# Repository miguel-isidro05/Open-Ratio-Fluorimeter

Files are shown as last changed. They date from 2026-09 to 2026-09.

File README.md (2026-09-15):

# Open-Ratio Fluorimeter

Repositorio de trabajo para la adaptación del fluorímetro ratiométrico de IO Rodeo. Reúne el firmware, las interfaces gráficas, las PCB, la carcasa y las evidencias experimentales desarrolladas durante la pasantía en la UPCH.

## Estado actual

Hay dos montajes documentados:

1. El IO Rodeo con PyBadge, pantalla integrada y adaptación para el sensor AS7341.
2. La versión de demostración con Arduino Mega 2560, AS7341, pantalla Nokia 5110, GUI de escritorio y cuatro placas LED intercambiables.

La PCB Excite V5 es la iteración más reciente del módulo de excitación y está orientada al uso de LED seleccionados por banda. La PCB Energy entrega las líneas de alimentación usadas por el montaje, incluida la alimentación de 5 V para el Arduino Mega y la línea de 12 V para la iluminación. La PCB Detector se conserva como avance de diseño, pero no forma parte del montaje actual porque la detección se realizará con un módulo AST.

## Contenido

| Sección | Contenido |
| --- | --- |
| [`Firmware/`](Firmware/) | Firmware del Arduino Mega y snapshots del IO Rodeo con PyBadge |
| [`Software/`](Software/) | GUI del Mega y GUI anterior para el IO Rodeo |
| [`Hardware/Electronics/`](Hardware/Electronics/) | PCB Excite, Energy y Detector, con sus iteraciones de fabricación |
| [`Hardware/3D_Models/`](Hardware/3D_Models/) | Carcasa final en STL |
| [`Experiments/`](Experiments/) | Videos, clips por LED, pósteres y datos registrados |
| [`Papers/`](Papers/) | Artículos de referencia reunidos para el proyecto |
| [`PROGRESS.md`](PROGRESS.md) | Cronología y relación entre versiones |
| [`VERIFICATION.md`](VERIFICATION.md) | Pruebas ejecutadas sobre la copia organizada |
| [`UPLOAD_CHECKLIST.md`](UPLOAD_CHECKLIST.md) | Revisión previa al commit y al envío a GitHub |

## Por dónde empezar

- Para reproducir la versión con Arduino Mega, consulta [`Firmware/Arduino_Mega_AS7341/`](Firmware/Arduino_Mega_AS7341/) y [`Software/Arduino_Mega_AS7341_GUI/`](Software/Arduino_Mega_AS7341_GUI/).
- Para revisar la progresión de la PCB de excitación, abre [`Hardware/Electronics/Excitation/README.md`](Hardware/Electronics/Excitation/README.md).
- Para ver la demostración por cada LED, abre [`Experiments/Arduino_Mega_4_LED/README.md`](Experiments/Arduino_Mega_4_LED/README.md).
- Para revisar el funcionamiento del IO Rodeo, abre [`Experiments/IO_Rodeo_AS7341/README.md`](Experiments/IO_Rodeo_AS7341/README.md).

## Criterio de archivo

Los nombres originales de los proyectos KiCad y de sus archivos de fabricación se conservaron para no romper referencias ni ocultar el historial. Las etiquetas de versión añadidas en esta organización describen el orden de trabajo encontrado en las carpetas. No sustituyen un número de revisión grabado en la PCB.

Los videos originales de cámara no se incluyen porque `IMG_7704.MOV` supera el límite habitual de GitHub. El repositorio contiene versiones H.264 más pequeñas, sin metadatos de ubicación, y un manifiesto con los hashes de los originales.

## Antes de usar el equipo

Revisa tensiones, polaridad, masa común y compatibilidad de niveles lógicos antes de energizar el montaje. Los archivos y las pruebas de software no certifican seguridad eléctrica, calibración óptica ni precisión metrológica.

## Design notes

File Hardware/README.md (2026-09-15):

# Hardware

## Electrónica

[`Electronics/`](Electronics/) contiene los proyectos KiCad y archivos de fabricación de Excite, Energy y Detector.

## Mecánica

[`3D_Models/Carcasa_v1/`](3D_Models/Carcasa_v1/) contiene la carcasa final en formato STL.

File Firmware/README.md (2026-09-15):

# Firmware

## Arduino Mega 2560

[`Arduino_Mega_AS7341/v1.0/`](Arduino_Mega_AS7341/v1.0/) contiene el sketch `.ino`, la implementación C++ y la prueba host del firmware usado con la GUI multicanal.

## IO Rodeo con PyBadge

[`IO_Rodeo_PyBadge/`](IO_Rodeo_PyBadge/) conserva tres estados:

- `reference_upstream`: referencia original del firmware multicanal. No se presenta como trabajo propio.
- `v2.0_tsl2591_gui`: snapshot con telemetría USB para la primera GUI de escritorio.
- `v3.0_as7341`: adaptación posterior con AS7341 a 90 grados y TSL2591 a 180 grados.

Los nombres `v2.0` y `v3.0` indican la secuencia de archivo dentro de este repositorio. Consulta el README de cada snapshot para conocer su función real.

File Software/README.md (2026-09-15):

# Software

## GUI para Arduino Mega y AS7341

[`Arduino_Mega_AS7341_GUI/v1.0/`](Arduino_Mega_AS7341_GUI/v1.0/) es la aplicación actual para el montaje de demostración. Muestra la telemetría multicanal, controla la adquisición y el PWM, refleja la Nokia y registra experimentos.

## GUI anterior para IO Rodeo y TSL2591

[`IO_Rodeo_TSL2591_GUI/v1.0/`](IO_Rodeo_TSL2591_GUI/v1.0/) es la primera interfaz PyQt para observar y controlar la copia TSL del firmware del PyBadge mediante USB CDC.

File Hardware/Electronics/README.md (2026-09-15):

# Electrónica

| Módulo | Función | Estado |
| --- | --- | --- |
| [`Excitation/`](Excitation/) | Etapa de excitación y montaje de LED | V5 es la iteración más reciente |
| [`Power/Energy/`](Power/Energy/) | Conversión y distribución de alimentación | Ruta final de FlatCAM conservada |
| [`Detection/Detector/`](Detection/Detector/) | Diseño de una etapa detectora | Archivada, no usada con el detector AST actual |

Los archivos KiCad conservan nombres internos como `Untitled` y `Excite_V1`. No se renombraron porque el nombre del archivo no basta para reconstruir todas sus referencias internas.

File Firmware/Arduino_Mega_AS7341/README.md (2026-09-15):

# Firmware para Arduino Mega y AS7341

La versión actual está en [`v1.0/`](v1.0/). El sketch usa un Arduino Mega 2560, un AS7341 y una pantalla Nokia 5110. La salida D11 controla la iluminación externa mediante PWM.

## Archivos principales

- `v1.0/firmware/mega_as7341_multichannel/mega_as7341_multichannel.ino`: entrada del sketch para Arduino IDE.
- `v1.0/firmware/mega_as7341_multichannel/firmware.cpp`: implementación del firmware.
- `v1.0/tests/firmware_host/`: dobles de las bibliotecas Arduino y prueba host.

## Cableado conservado en el firmware

| Señal | Arduino Mega 2560 |
| --- | --- |
| AS7341 SDA | D20 / SDA |
| AS7341 SCL | D21 / SCL |
| Nokia SCLK | D52 |
| Nokia DIN / MOSI | D51 |
| Nokia DC | D5 |
| Nokia CE | D4 |
| Nokia RST | D3 |
| PWM LED | D11 |

Verifica el voltaje admitido por cada módulo antes de conectarlo. La asignación de pines no certifica compatibilidad con lógica de 5 V.

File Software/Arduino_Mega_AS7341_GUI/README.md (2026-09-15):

# GUI para Arduino Mega y AS7341

La versión actual está en [`v1.0/`](v1.0/). Usa PyQt y un protocolo serial JSON Lines para controlar el firmware del Mega sin sustituir las lecturas realizadas por el microcontrolador.

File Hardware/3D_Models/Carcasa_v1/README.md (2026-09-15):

# Carcasa final

Archivo: [`carcasa_final.stl`](carcasa_final.stl)

El STL es binario y contiene 13 430 triángulos. Su caja envolvente es 36.30 x 38.80 x 58.90 unidades. El formato STL no declara unidades; si el modelo fue exportado en milímetros, esas dimensiones corresponden a milímetros.

Hash SHA-256 del archivo original y de esta copia:

```text
de2bfdceeedc73f0b56ba4e6553f56c1a85680b48ca6d725923ace9b68575b5c
```

Antes de imprimir, confirma unidades, orientación, tolerancias, agujeros y espacio para conectores y cableado.

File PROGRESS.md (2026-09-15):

# Progresión del proyecto

Esta cronología reúne fechas visibles en los respaldos, documentos y archivos del proyecto. Cuando una carpeta no tiene un registro formal de cambios, se describe solo lo que puede verificarse en sus artefactos.

## Abril de 2026

- 14 de abril: primeros respaldos de Excite V1 y Detector V1.
- 15 de abril: primera preparación de archivos Gerber, perforado y mecanizado para Excite y Energy.
- 21 al 22 de abril: segundas iteraciones de FlatCAM para Excite y Energy.
- 25 de abril: archivos de fabricación de Excite V3 y modelo STEP asociado.
- 27 de abril: respaldo posterior del proyecto KiCad Excite V1.

## Mayo de 2026

- 5 y 6 de mayo: consolidación de la ruta de fabricación final de Energy. La carpeta `flatcam_vfinal` conserva proyectos FlatCAM, mapas, pista y taladro.

## Agosto de 2026

- 26 de agosto: diseño de la comunicación serial y de la GUI UPCH.
- 27 de agosto: diseño de la adaptación para Arduino Mega, adquisición multicanal y pantalla externa.

## Septiembre de 2026

- 8 de septiembre: registro visual del IO Rodeo funcionando con el AS7341. También aparecen respaldos recientes del proyecto Excite.
- 11 de septiembre: control PWM de la salida LED desde la GUI y firmware Mega 2.3.0. Se añadieron trazabilidad de PWM y validaciones de compatibilidad.
- 12 de septiembre: módulos de experimentos, blancos, cocientes, calibración, resultados y controles de calidad. Quedó pendiente la validación óptica con el montaje real.
- 14 de septiembre: escala Y automática opcional en la GUI y registro de la demostración con cuatro placas LED.

## Relación entre ramas

| Rama | Controlador | Sensor principal | Pantalla | Software de escritorio |
| --- | --- | --- | --- | --- |
| IO Rodeo adaptado | PyBadge | AS7341 a 90 grados y TSL2591 a 180 grados | Integrada en el equipo | GUI TSL anterior, cuando se usa el firmware con telemetría |
| Demostración Mega | Arduino Mega 2560 | AS7341 | Nokia 5110 | GUI multicanal en PyQt |

## Estado de las PCB

- Excite V5 es la iteración de fabricación más reciente y se conserva como la versión actual para LED específicos por banda.
- Energy conserva la fuente KiCad, dos rutas FlatCAM previas, una ruta final y archivos para corte láser.
- Detector V1 se archiva como diseño no utilizado en el montaje AST actual.

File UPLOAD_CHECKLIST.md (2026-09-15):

# Lista de revisión para GitHub

## Contenido

1. Abre `README.md` y comprueba que la descripción del estado actual coincide con el montaje físico.
2. Revisa `PROGRESS.md` y completa cualquier fecha o cambio eléctrico que no esté registrado en los nombres de archivo.
3. Confirma que los cuatro clips representan el LED correcto. Los LED 3 y 4 no tienen longitud de onda nominal asignada porque el video no identifica el componente.
4. Revisa los datos de `Experiments/Arduino_Mega_4_LED/data/` y retira cualquier sesión que no deba publicarse.
5. Confirma la licencia de `Firmware/IO_Rodeo_PyBadge/reference_upstream/`.

## Archivos de macOS

`.DS_Store` está ignorado para archivos nuevos. Si el repositorio ya tenía copias rastreadas, Git seguirá mostrándolas hasta retirarlas del índice o restaurarlas. Revísalas por separado antes de usar `git add .`.

## Comprobaciones locales

```bash
git status --short
git diff --check
find . -type f -size +95M -print
```

No debería aparecer ningún archivo nuevo por encima de 95 MB. Los videos derivados actuales están por debajo de 46 MB cada uno.

## Preparar el commit

```bash
git add .
git status --short
git commit -m "Organiza avances del fluorimetro y documenta versiones"
git push
```

Revisa la lista de `git status` antes de confirmar. Este documento describe los comandos, pero no sustituye la revisión del contenido que se hará público.

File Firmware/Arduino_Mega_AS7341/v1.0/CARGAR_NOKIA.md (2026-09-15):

# Firmware Mega + AS7341 + Nokia 5110 - 2.3.0

El programa se sube al **Arduino Mega 2560**, no directamente a la Nokia.

1. Cierra la conexión de la GUI y el monitor serie del IDE.
2. Abre `firmware/mega_as7341_multichannel/mega_as7341_multichannel.ino` en Arduino IDE. Mantén `firmware.cpp` en la misma carpeta: contiene la implementación y el IDE lo compila junto al sketch.
3. Selecciona Arduino Mega or Mega 2560, procesador ATmega2560 y el puerto USB del equipo.
4. Pulsa Subir. Espera «Done uploading».
5. Reinicia la GUI actualizada y conecta el mismo puerto a 115200 baudios.
6. En **Adquisición en vivo**, verifica Ganancia, Integración y **PWM LED D11**. El valor inicial debe indicar 25 %.

La versión 2.3.0 conserva sin cambios la adquisición validada con la API pública de Adafruit, el orden F1-F8/CLEAR/NIR, 128x/300ms al iniciar y el watchdog. El único cambio funcional del firmware es que el PWM de D11 ahora puede ajustarse desde la GUI entre 0 y 100 %.

Cableado actual: AS7341 SDA→20, SCL→21. Nokia CLK→52, DIN→51, DC→5, CE→4, RST→3. La salida PWM del LED externo es D11 y comienza en 25 % (`analogWrite(64)`). GND común. La alimentación y adaptación de niveles dependen del módulo: no conectes señales de 5 V directamente a una Nokia o sensor que no las tolere.

**Iniciar grabación** y **Detener y guardar CSV** controlan el registro. **Pausar gráfica** no detiene la recepción ni el CSV. Cada fila conserva las diez bandas, fecha UTC, secuencia, tiempo del Mega, ganancia, integración, porcentaje PWM y valor PWM raw.

La escala vertical es manual y fija. La gráfica no inventa muestras intermedias: la frecuencia real depende de la integración y lectura del sensor. La validación física de la Nokia y sus niveles eléctricos queda pendiente de la prueba en el equipo.

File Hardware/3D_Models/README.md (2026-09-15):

# Modelos 3D

[`Carcasa_v1/`](Carcasa_v1/) contiene la carcasa final recibida para este estado del proyecto.

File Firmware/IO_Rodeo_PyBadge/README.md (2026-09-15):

# Firmware del IO Rodeo con PyBadge

## `reference_upstream`

Código de referencia del proyecto multichannel colorimeter. Se conserva para comparar la base con las adaptaciones de la UPCH. Revisa su licencia y README originales antes de redistribuirlo.

Consulta [`reference_upstream/ARCHIVE_NOTES.md`](reference_upstream/ARCHIVE_NOTES.md) antes de usar sus ejemplos.

## `v2.0_tsl2591_gui`

Snapshot basado en el firmware `latest` que agrega un segundo puerto USB CDC. Ese puerto permite a la primera GUI recibir telemetría y enviar cambios de modo, ganancia, integración y normalización.

## `v3.0_as7341`

Snapshot que añade AS7341 a 90 grados en el canal 3 del PCA9546A y conserva un TSL2591 a 180 grados en el canal 0. Incluye la opción `Multichannel 90`, con dos páginas para los diez canales del AS7341.

Para instalar un snapshot, copia su contenido completo a la raíz de `CIRCUITPY`. No mezcles archivos entre snapshots.

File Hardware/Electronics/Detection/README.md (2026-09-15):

# Detección

[`Detector/`](Detector/) conserva el diseño de la etapa detectora desarrollada durante la adaptación.

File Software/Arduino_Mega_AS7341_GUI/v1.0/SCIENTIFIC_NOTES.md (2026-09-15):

# Base experimental y límites

Documentos locales examinados en `../Papers`, relativos a la carpeta FIRMWARE_IORODEO. La adaptación de software no reproduce ni valida las prestaciones de esos instrumentos.

| PDF | Evidencia consultada | Aplicación en la GUI |
| --- | --- | --- |
| Ratiometric design.pdf | Zhou et al., 2026, DOI 10.1016/j.microc.2026.118982, página PDF 2: cocientes entre emisiones seleccionadas y referencias internas | Selección explícita de canales y orientación A/B. No se asignan automáticamente bandas a un fluoróforo. |
| low_cost_1.pdf | Chen et al., Talanta 269, 125447, páginas PDF 4 y 5: estándares de concentración, promediado, ajuste lineal y mediciones replicadas | Promedio de N lecturas posteriores al clic; desviación estándar guardada; calibración con estándares, R² y RMSE. |
| low_cost_2.pdf | Power et al., DOI 10.1039/d3ay00991b, página PDF 1: fluorómetro con varias fuentes LED y detección multiespectral | Identificación manual de LED y conservación de todos los canales. El cociente de dos excitaciones es una adaptación experimental, no una equivalencia validada con ese artículo. |
| low_cost_3.pdf | Faghir Hagh et al., DOI 10.1109/JSEN.2024.3403416, página PDF 1: distintas excitaciones, calibración con patrones y almacenamiento local | Separación de condiciones de iluminación, puntos trazables y exportación. No se reproducen LoRa, turbidez ni conversiones de pigmentos. |
| Open-JIP.pdf | Bates et al., DOI 10.1007/s11120-019-00673-2, página PDF 1: protocolo OJIP y rendimiento fotoquímico | Define una limitación: no calcular Fv/Fm ni OJIP desde capturas manuales lentas del AS7341. |

## Métodos implementados

- LED sucesivos: colocar LED A, esperar estabilidad, capturar; cambiar manualmente a LED B, esperar y capturar. R = media del canal A bajo LED A / media del canal B bajo LED B. Se pueden elegir el mismo canal o canales diferentes. La deriva entre exposiciones no se cancela automáticamente.
- Referencia óptica: Q = emisión medida / excitación de referencia medida. Ambas son capturas sucesivas del AS7341, conservadas con su configuración. Es un cociente instrumental, no eficiencia cuántica ni irradiancia calibrada. La geometría y la respuesta espectral deben caracterizarse experimentalmente.
- Blanco: no se permite usarlo como denominador. En Blanco y fondo se captura por separado, identificado por exposición. La corrección explícita conserva S = media(señal) - media(blanco), incluso si es negativa. Se exige igualdad de exposición, protocolo, ganancia, integración y PWM. Para corregir un cociente se seleccionan los blancos de A y B: R = (A - blanco A) / (B - blanco B). Señal y referencia corregidas deben ser positivas para informar ese cociente.
- Calibración: y = m c + b por mínimos cuadrados ordinarios, intercepto libre. Se requieren tres concentraciones distintas; cada clic de intensidad recoge una nueva captura. Los cocientes guardados solo pueden añadirse una vez por par de capturas. No se mezclan canales, métodos, unidades ni ajustes del sensor. Los estándares replicados se conservan como puntos separados.
- El R² y el RMSE describen el ajuste a esos puntos. No constituyen validación externa ni estimación de LOD/LOQ. Las N lecturas consecutivas de una captura no son N réplicas independientes del ensayo.

Cada captura conserva cuentas crudas, media, desviación estándar, secuencias, tiempo del dispositivo, hora de finalización de captura, etiqueta, ganancia, integración y protocolo óptico declarado. El CSV guarda la hora de recepción de cada lectura. Se rechazan cuentas de 65535, denominador cero y cambios de configuración. Esto no certifica ausencia de saturación analógica ni linealidad. Se usa la integración nominal reportada por el firmware; no se aplica una conversión radiométrica entre bandas.

## Resultados y calidad (2026-09-12)

Esta sección interpreta el experimento actual o un JSON recuperado. No modifica el firmware, las cuentas, la gráfica en vivo ni los controles validados.

- Señales y réplicas muestra componentes raw, blancos y restas; media, SD y número de lecturas; ganancia, integración, PWM, exposición e IDs. Con una sola lectura la SD se muestra como no disponible. La SD de una resta o cociente no se obtiene por propagación automática: no se ha caracterizado la dependencia entre las lecturas y exposiciones.
- Los resultados con el mismo ID de muestra y firma experimental se agrupan como repeticiones del ensayo completo. Se informa media, SD muestral y RSD = 100 SD / |media| con al menos dos ensayos. Un resultado A/B requiere capturas nuevas de ambos componentes. Si comparten señal o referencia, la estadística de réplicas se bloquea; si comparten blancos se advierte de posible correlación y deriva. La SD es descriptiva, no incertidumbre total ni precisión certificada.
- Calibración e interpretación muestra puntos, valores ajustados y residuos (medido menos ajustado), R² y RMSE = raíz de la media de residuos al cuadrado. Estima c = (y - b) / m solo con método y unidad compatibles y una captura que no pertenezca a los estándares. Se bloquea extrapolar y se retienen los límites de concentración calibrados. El ajuste es ordinario, no ponderado, y no certifica linealidad: deben revisarse residuos y controles independientes.
- El aviso de referencia baja compara el denominador con un umbral editable en cuentas (inicialmente 1). Es un criterio operativo que impide informar concentración desde un cociente de referencia baja; no constituye un límite validado de señal/ruido, detección o cuantificación. Se conservan el cociente y su evidencia.
- Un blanco o una señal corregida no positiva no recibe concentración. Tampoco se atribuye una firma completa de calibración a resultados históricos versión 2. Se recupera su evidencia y se recalcula lo verificable; para continuar un ensayo se necesitan capturas nuevas.
- Exportar resultados CSV conserva IDs, configuraciones, método, valor raw y derivado, blancos, estadísticas, advertencias y concentración cuando procede. Incluye capturas y resultados guardados, diferenciados por evidence_type; la fila de una captura que aparece también como componente de un resultado no es una réplica adicional. El destino inicial es records/. El JSON versión 3 contiene las lecturas completas y se valida contra ellas al recuperarlo. Un CSV de adquisición raw no contiene por sí solo la asignación de blancos, muestras y estándares necesaria para reconstruir el ensayo.

## Bibliografía de los cálculos nuevos

1. Chen, X., et al. (2024). *A low-cost and portable fluorometer based on an optical pick-up unit for chlorophyll-a detection*. Talanta, 269, 125447. [DOI](https://doi.org/10.1016/j.talanta.2023.125447). Archivo local low_cost_1.pdf, página PDF 5, secciones 2.5 y 3.1: diferencia entre promediado de lecturas y tres pruebas separadas por concentración. Se adapta esa distinción; no se transfieren sensibilidad, LOD ni prestaciones del instrumento publicado.
2. Cantwell, H. (ed.) (2025). *Blanks in Method Validation*, 2.ª ed. Eurachem. [Guía](https://www.eurachem.org/images/stories/Guides/pdf/MV_Guide_Blanks_supplement_2nd_ed_EN.pdf). Página PDF 11 (página impresa 4), sección 3: tipos y usos del blanco. La guía orienta su elección; la corrección rutinaria de baseline queda fuera de su alcance explícito (página PDF 10). No se cita como prescripción de nuestra fórmula de resta.
3. Marston, D. J., Slattery, S. D., Hahn, K. M., y Tsygankov, D. (2021). *Correcting Artifacts in Ratiometric Biosensor Imaging; an Improved Approach for Dividing Noisy Signals*. Frontiers in Cell and Developmental Biology, 9, 685825. [DOI](https://doi.org/10.3389/fcell.2021.685825), [texto completo](https://pmc.ncbi.nlm.nih.gov/articles/PMC8418531/). Ecuación 2: cociente con resta de fondo en ambos componentes. Resultados, apartados sobre división por señales débiles: corregir el fondo no elimina los artefactos de denominadores ruidosos. Se adapta la operación a cuentas del AS7341, no la validación de imagen celular ni el método NCF propuesto por los autores.
4. NIST/SEMATECH. *e-Handbook of Statistical Methods*, sección 2.3.6.6, [Using the calibration curve](https://itl.nist.gov/div898/handbook/mpc/section3/mpc366.htm). Respalda la inversión de y = a + b x para recuperar x con el mismo instrumento y proceso controlado. La GUI no incorpora todavía el cálculo completo de incertidumbre de la concentración.
5. Zhou, M., et al. (2026). *Ratiometric fluorescence arrays: a review of design strategies, signal decoding, mechanisms, and applications*. Microchemical Journal, 228, 118982. [DOI](https://doi.org/10.1016/j.microc.2026.118982). Archivo local Ratiometric design.pdf, página PDF 2: cocientes de emisiones y referencias internas. Un LED externo o una referencia capturada sucesivamente no garantizan autocorrección de deriva, geometría o potencia de excitación.
6. DeRose, P. C. (2008). *Standard Guide to Fluorescence: Instrument Calibration and Validation*. NISTIR 7458. [DOI](https://doi.org/10.6028/NIST.IR.7458). Referencia de alcance metrológico: los derivados de cuentas no equivalen a irradiancia, concentración universal ni eficiencia cuántica sin calibración y validación del sistema óptico.

Las referencias están disponibles dentro de Resultados y calidad, en Métodos y bibliografía. Consulta de páginas y PDFs realizada el 2026-09-12. Se verificaron los PDFs locales directamente con pdftotext; no se utilizó PaperQA2 para estas comprobaciones.

## Uso

Ejecutar `desktop_gui/app.py` con las dependencias del proyecto. En Experimentos y calibración, introducir el ID de muestra, el protocolo óptico y N lecturas. Mantener el ID al repetir un ensayo de la misma muestra. Exposición identifica la condición actual (LED, filtro y posición); no debe cambiar entre blanco y señal de esa condición. El protocolo general describe ambas exposiciones A/B y debe mantenerse durante el ensayo y la curva.

En Blanco y fondo, seleccionar el canal y capturar blanco y señal por separado. Seleccionar ambos registros y guardar intensidad corregida. Para LED sucesivos o Baseline y referencia, capturar A y B; si se desea corrección, marcarla y seleccionar el blanco de cada exposición. No hay asignación automática de blancos. Cada resultado exige un ensayo A/B nuevo. El firmware descarta la integración anterior al comando, espera la estabilización y etiqueta las muestras nuevas.

En Curva de calibración, elegir intensidad raw, intensidad con blanco o último cociente guardado. Introducir concentración conocida y unidad; guardar cada estándar, con al menos tres niveles distintos, y ajustar. Para medir una muestra desconocida no se añade un punto de concentración supuesta: se captura señal o un ensayo A/B y se consulta Resultados y calidad. Abrir un JSON recupera evidencia sin convertirla en ensayo activo. Guardar experimento JSON conserva la evidencia completa; los CSV entregan tablas de adquisición, estándares o derivados según el botón utilizado.

## Revisión de interfaz

| Antes | Después | Motivo |
| --- | --- | --- |
| Adquisición, controles y actividad en una única vista | Pestañas de adquisición y experimentos; etapas de captura explícitas | Separar la lectura en vivo de las acciones experimentales. |
| Selectores enviaban índices; CSV fallaba con campo extra | Envío de texto del selector y filas CSV planas probadas | Evitar comandos rechazados y pérdida de exportación. |
| Eje espectral equidistante | Posiciones por longitud de onda y exclusión de saturados | No representar separaciones espectrales falsas ni saturación como señal cuantitativa. |

Apple HIG orientó jerarquía, controles legibles y estados explícitos; Emil orientó respuestas inmediatas sin animaciones decorativas durante adquisición.

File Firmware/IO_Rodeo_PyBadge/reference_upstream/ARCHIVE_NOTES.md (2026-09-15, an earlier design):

# Notas de la referencia upstream

Esta carpeta conserva el código de referencia para comparación y atribución. No se presenta como una versión lista para cargar en el montaje actual.

`examples/configuration.json` contiene una coma final en el objeto original y no es JSON estricto. Se conserva para no ocultar una diferencia del material de referencia. Para el montaje adaptado, usa el archivo `configuration.json` del snapshot `v2.0_tsl2591_gui` o `v3.0_as7341` correspondiente.

El enlace a la imagen del README se ajustó a una ruta relativa para que funcione dentro de este repositorio. El código y la licencia se conservan en la carpeta.

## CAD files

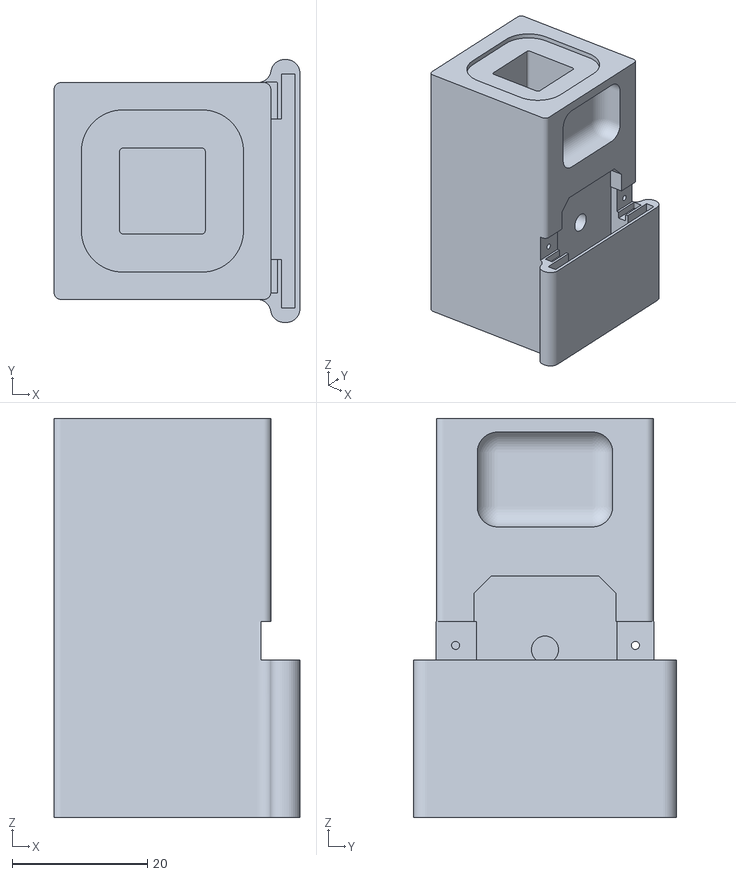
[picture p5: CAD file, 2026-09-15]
Hardware/3D_Models/Carcasa_v1/carcasa_final.stl
36.3 x 38.8 x 58.9

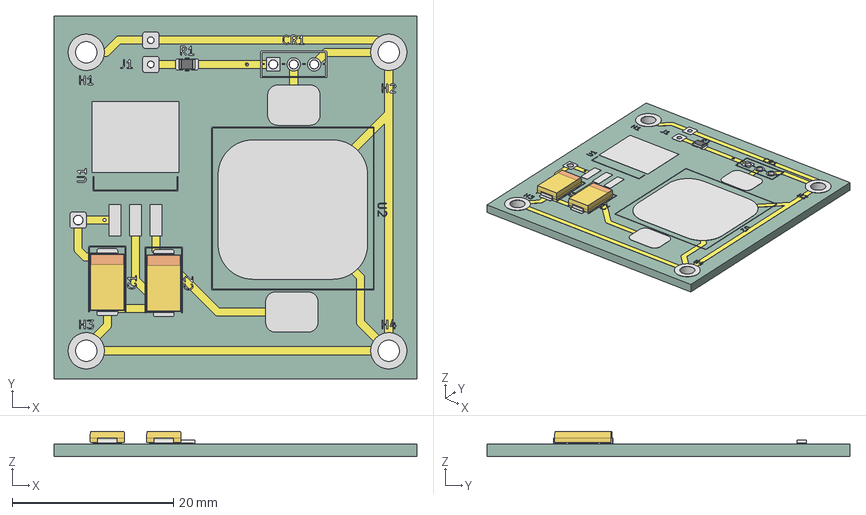
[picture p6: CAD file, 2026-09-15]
Hardware/Electronics/Excitation/Excite_V1/Excite_V1.step
45.0 x 45.0 x 3.13 mm
CP_EIA-7343-15_Kemet-W x 2
R_0805_2012Metric
Excite_V1_copper
Excite_V1_pad
Excite_V1_silkscreen
Excite_V1_PCB

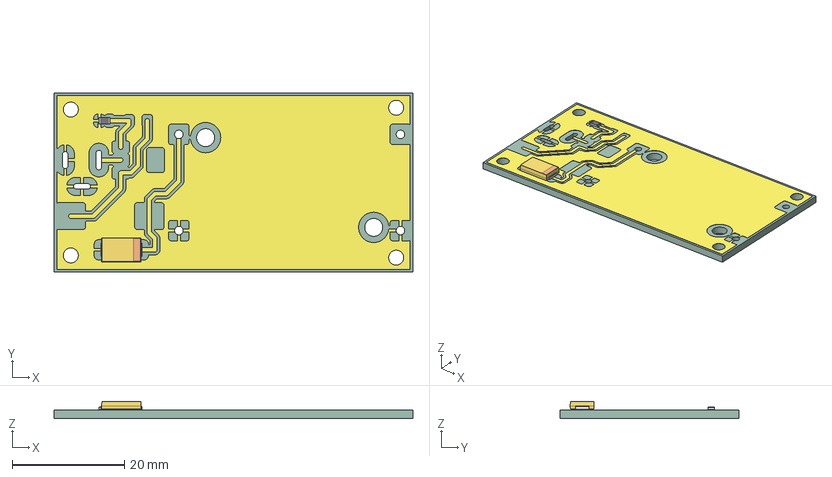
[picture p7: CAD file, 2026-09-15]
Hardware/Electronics/Power/Energy/Energia .step
64.0 x 32.0 x 3.09 mm
R_0805_2012Metric
CP_EIA-7343-15_Kemet-W
Untitled_copper
Untitled_PCB

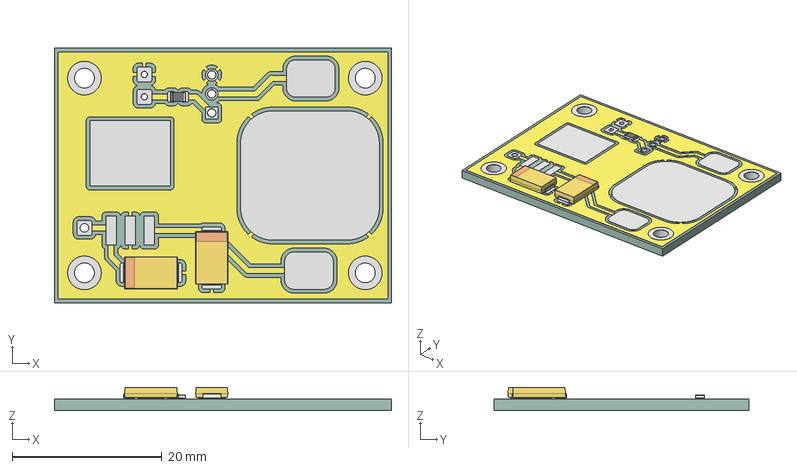
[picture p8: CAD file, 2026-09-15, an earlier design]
Hardware/Electronics/Excitation/flatcam_files_v3/Excite_V3.step
45.0 x 34.0 x 3.13 mm
CP_EIA-7343-15_Kemet-W x 2
R_0805_2012Metric
Excite_V1_copper
Excite_V1_pad
Excite_V1_PCB

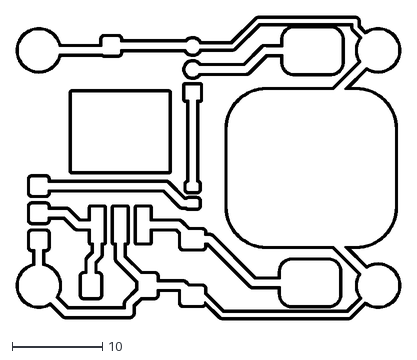
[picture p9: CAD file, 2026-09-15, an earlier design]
Hardware/Electronics/Excitation/flatcam_files_v4_laser/pista_1.DXF
42.5 x 33.5

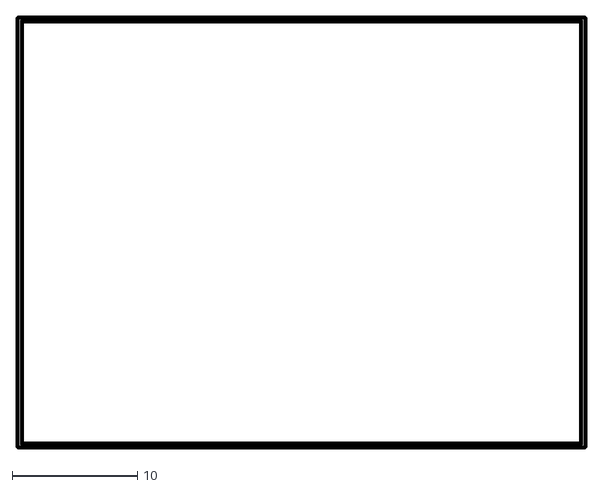
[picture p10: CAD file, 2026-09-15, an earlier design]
Hardware/Electronics/Excitation/flatcam_files_v4_laser/cut.DXF
45.6 x 34.6

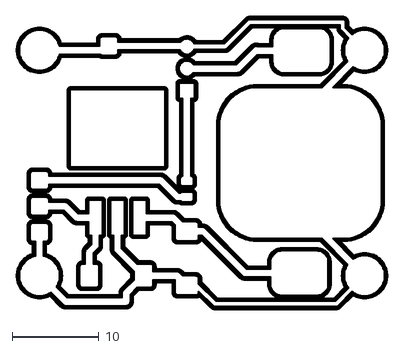
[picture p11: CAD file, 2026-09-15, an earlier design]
Hardware/Electronics/Excitation/flatcam_files_v4_laser/pista_2.DXF
42.8 x 33.8

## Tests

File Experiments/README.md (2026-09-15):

# Experimentos y demostraciones

## IO Rodeo con AS7341

[`IO_Rodeo_AS7341/`](IO_Rodeo_AS7341/) muestra el funcionamiento del equipo IO Rodeo con su pantalla integrada y el montaje óptico.

## Arduino Mega con cuatro LED

[`Arduino_Mega_4_LED/`](Arduino_Mega_4_LED/) contiene la demostración de la GUI, el Arduino Mega, el AS7341 y cuatro placas LED. El video original se dividió por etapa para que cada resultado pueda revisarse y enlazarse por separado.

Los videos son evidencia funcional, no una calibración de longitud de onda, potencia óptica ni linealidad.

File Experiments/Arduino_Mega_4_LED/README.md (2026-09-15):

# Demostración con Arduino Mega y cuatro LED

Esta demostración conecta el Arduino Mega 2560, el AS7341 y la GUI de escritorio. Cuatro placas LED se ensayan de forma sucesiva para observar el cambio de la respuesta multicanal.

## Montaje mostrado

- Arduino Mega 2560.
- Sensor AS7341.
- Pantalla Nokia 5110 conectada al firmware.
- GUI PyQt ejecutándose en la computadora.
- Cuatro placas LED intercambiables que no corresponden al LED de 12 V del módulo Excite final.

## Clips

| Etapa | Evidencia | Duración |
| --- | --- | ---: |
| LED 1, emisión azul visible | [`01_LED_AZUL.md`](01_LED_AZUL.md) | 39 s |
| LED 2, emisión ámbar visible | [`02_LED_AMBAR.md`](02_LED_AMBAR.md) | 64 s |
| LED 3 | [`03_LED_3.md`](03_LED_3.md) | 64 s |
| LED 4 | [`04_LED_4.md`](04_LED_4.md) | 34.17 s |

## Cómo reproducir la prueba

1. Carga el firmware de [`../../Firmware/Arduino_Mega_AS7341/v1.0/`](../../Firmware/Arduino_Mega_AS7341/v1.0/).
2. Instala e inicia la GUI de [`../../Software/Arduino_Mega_AS7341_GUI/v1.0/`](../../Software/Arduino_Mega_AS7341_GUI/v1.0/).
3. Conecta el puerto serial a 115200 baudios y espera la verificación del equipo.
4. Fija ganancia, integración y PWM. Anota cualquier cambio entre LED.
5. Con la alimentación desactivada, sustituye la placa LED.
6. Enciende la iluminación, espera estabilización y observa el espectro.
7. Inicia una grabación o captura experimental y guarda los datos.
8. Repite con el mismo montaje geométrico y condiciones comparables.

## Interpretación

Una variación en la curva demuestra que el sensor y la GUI responden al cambio de fuente. No permite asignar una longitud de onda nominal a cada LED ni comparar intensidades absolutas sin calibración, control de corriente, filtros y geometría constantes.

Los registros disponibles están en [`data/`](data/). Son datos de avance y deben revisarse antes de usarlos en un análisis científico.

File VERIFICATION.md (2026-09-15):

# Verificación de la copia organizada

Fecha de verificación: 14 de septiembre de 2026.

## Firmware del Arduino Mega

- Prueba C++ host aprobada: API pública del AS7341, canales raw, configuración, parser, display, barrera de captura y PWM.
- Compilación para `arduino:avr:mega` aprobada con Arduino AVR core 1.8.8.
- Uso informado por el compilador: 27 058 bytes de flash y 3 181 bytes de RAM estática.

## GUI

- GUI del Arduino Mega: 63 de 63 pruebas aprobadas en modo Qt offscreen.
- GUI histórica del IO Rodeo: 13 de 13 pruebas aprobadas.
- La prueba de integración de la GUI histórica se ajustó para localizar el firmware en `Firmware/IO_Rodeo_PyBadge/v2.0_tsl2591_gui/`. Una revisión independiente no encontró regresiones en ese cambio.

## Documentación y archivos

- 51 archivos Markdown revisados sin enlaces locales faltantes.
- Los archivos fuente copiados de Excite, Energy, Detector, firmware Mega y GUI Mega coinciden con sus originales, salvo exclusiones documentadas de cachés y archivos temporales.
- No hay archivos nuevos mayores de 95 MB.
- No se copiaron entornos virtuales, cachés Python, `fp-info-cache`, archivos `.kicad_prl` ni videos MOV originales.

## Medios

- Los cuatro clips del Mega y el video del IO Rodeo decodifican completos, con video y audio, sin errores de FFmpeg.
- Los derivados no contienen etiquetas de ubicación.
- Los intervalos y hashes de los originales están en `Experiments/MEDIA_MANIFEST.md`.

## Limitación conocida

`Firmware/IO_Rodeo_PyBadge/reference_upstream/examples/configuration.json` conserva una coma final del material de referencia y no es JSON estricto. No se usa como configuración de los snapshots adaptados.

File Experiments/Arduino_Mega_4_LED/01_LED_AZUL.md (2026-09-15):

# LED 1, emisión azul visible

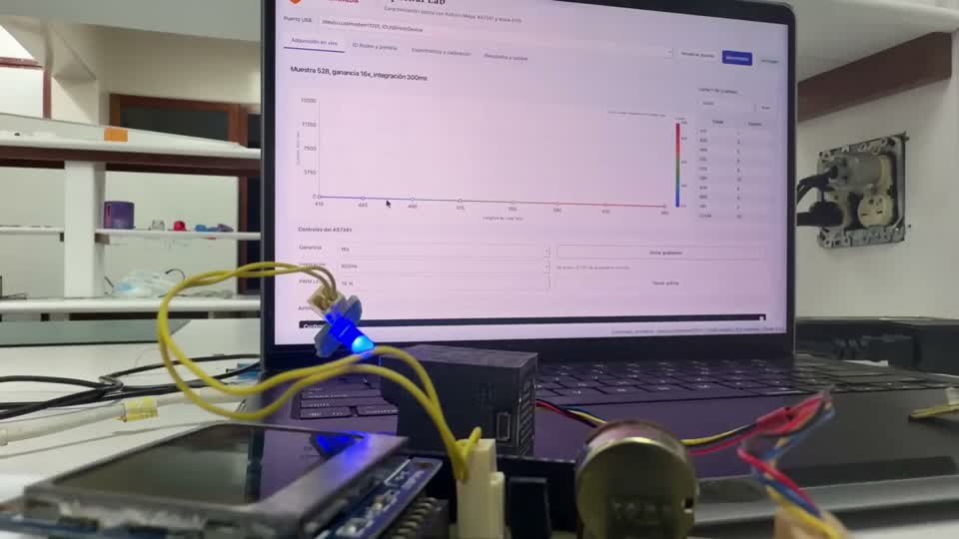
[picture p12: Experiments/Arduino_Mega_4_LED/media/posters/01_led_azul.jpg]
Demostración del LED azul


[Abrir el clip MP4](media/clips/01_led_azul.mp4)

Intervalo en el original: 00:00.000 a 00:39.000.

La placa emite luz azul visible frente al AS7341. La GUI recibe cuentas del firmware y representa la respuesta por bandas. El clip también muestra la manipulación previa al cambio de placa.

Para repetirlo, conserva la misma distancia y orientación entre LED y sensor. Registra ganancia, integración y PWM antes de guardar una captura.

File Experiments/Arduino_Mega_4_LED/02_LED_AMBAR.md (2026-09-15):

# LED 2, emisión ámbar visible

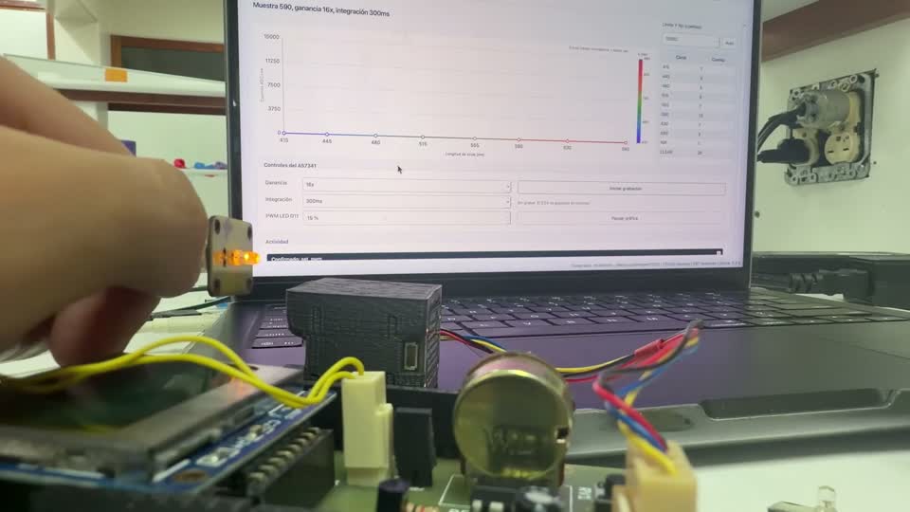
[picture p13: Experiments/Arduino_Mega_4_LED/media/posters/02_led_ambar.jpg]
Demostración del LED ámbar


[Abrir el clip MP4](media/clips/02_led_ambar.mp4)

Intervalo en el original: 00:39.000 a 01:43.000.

La segunda placa muestra una emisión ámbar visible. Durante esta etapa se observa la respuesta de la GUI y la interacción con sus controles.

El color observado por la cámara es una referencia visual. La banda central del LED debe confirmarse con su ficha técnica o una medición espectral calibrada.

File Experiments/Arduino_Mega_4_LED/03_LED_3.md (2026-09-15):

# LED 3

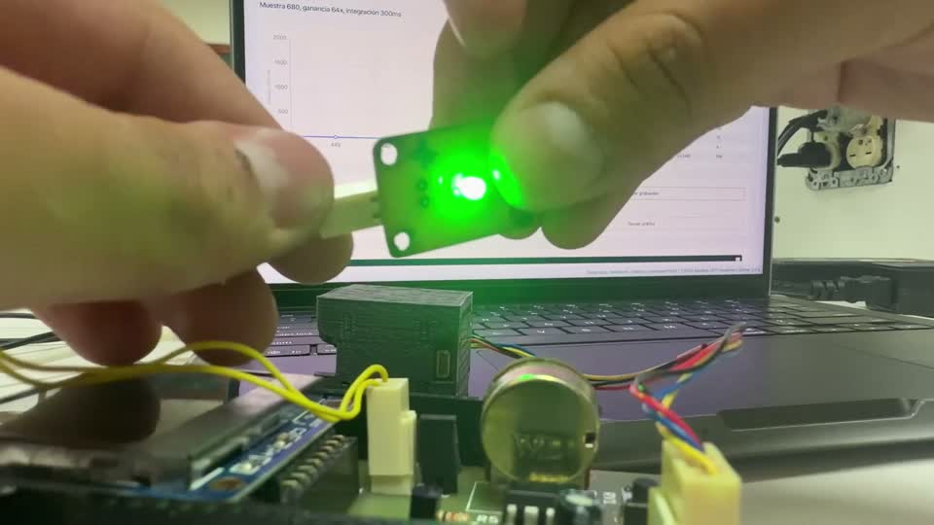
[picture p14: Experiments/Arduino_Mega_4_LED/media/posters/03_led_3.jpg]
Demostración del tercer LED


[Abrir el clip MP4](media/clips/03_led_3.mp4)

Intervalo en el original: 01:43.000 a 02:47.000.

La tercera placa se conecta y su emisión se observa como verde intensa en la cámara. La GUI muestra una distribución distinta de cuentas entre las bandas del AS7341.

No se asigna una longitud de onda nominal porque el video no aporta la identificación del componente. Documenta el código del LED y su corriente cuando se repita el ensayo.

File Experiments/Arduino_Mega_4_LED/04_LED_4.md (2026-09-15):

# LED 4

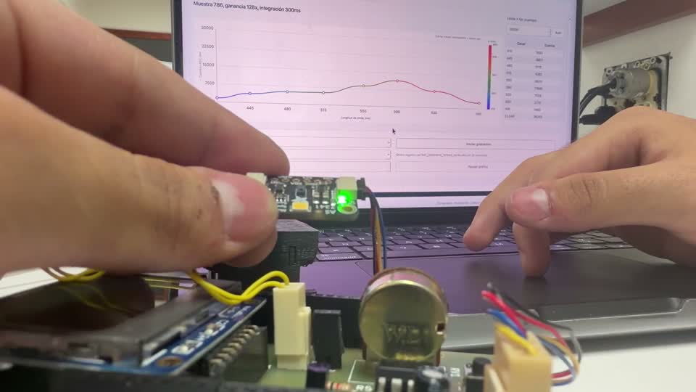
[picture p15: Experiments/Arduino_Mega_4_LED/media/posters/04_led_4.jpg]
Demostración del cuarto LED


[Abrir el clip MP4](media/clips/04_led_4.mp4)

Intervalo en el original: 02:47.000 a 03:21.165.

La cuarta placa tiene un diseño físico distinto. En el clip se observa una emisión verde y una curva amplia en la GUI. La etapa incluye la conexión, la presentación de la placa y la respuesta recibida.

La comparación con el LED 3 debe hacerse con los valores raw y la configuración guardada, no solo con la apariencia de la cámara.

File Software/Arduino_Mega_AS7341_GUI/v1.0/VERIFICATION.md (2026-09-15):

# Verificación de firmware y GUI

Fecha: 2026-09-14. Proyecto aislado; no se modificaron `upch_GUI` ni `upch_firmware`.

## Resultados

- 63 pruebas Python/Qt aprobadas en modo offscreen con el entorno `desktop_gui/.venv`.
- Seis pruebas de escala Auto: modo fijo inicial, ajuste y retorno manual, exclusión de NIR/Clear/OVFL, límites, pausa/reanudación, ausencia de comandos al firmware y transiciones animadas válidas o saturadas. Revisión visual del botón a 980 × 680 con datos simulados.
- Nuevas pruebas: resta con signo, blancos por exposición, cocientes corregidos, ensayos completos frente a lecturas seriales, no reutilización de señal como réplica, compatibilidad de calibración, inversión conocida y bloqueo de extrapolación/autopredicción del estándar.
- Recuperación v2→v3→recuperación verificada con cocientes y puntos. Un archivo con resultado/componentes alterados, firma incompatible o concentración excesiva se rechaza; la sesión actual se conserva.
- Exportación CSV verificada para resultados, captura raw de muestra desconocida y captura saturada (sin falsa concentración). El CSV diferencia filas de captura y resultado con `evidence_type`; ambas no deben contarse como réplicas adicionales.
- Revisión de código realizada; los hallazgos sobre blancos y números JSON excesivos se corrigieron y probaron.
- Prueba C++ con sensor, pantalla y UART simulados aprobada: API pública del AS7341, orden raw, ganancias, integraciones, parser, display, captura, negociación de capacidad y PWM D11 en 0 %, 25 %, 50 % y 100 %.
- Compilación real previa del 2026-09-11 para `arduino:avr:mega`, core AVR 1.8.8, con advertencias habilitadas: 27058 bytes de flash (10 %) y 3181 bytes de RAM estática (38 %). Esta ampliación no modifica el firmware ni requiere otra carga.
- Revisión visual offscreen de las secciones nuevas a 980 × 680 y 1100 × 900. Controles y tablas disponen de desplazamiento para conservar acceso a detalles e IDs. Las pruebas de adquisición, escala fija, pausa, grabación y espejo IO Rodeo siguen pasando.

## Repetir las pruebas

Desde la raíz de este proyecto, con PyQt6 y pyserial instalados:

```bash
QT_QPA_PLATFORM=offscreen PYTHONPATH=desktop_gui desktop_gui/.venv/bin/python -m unittest discover -s tests -v
clang++ -std=c++17 -Wall -Wextra -I tests/firmware_host -I .arduino/libraries/ArduinoJson/src tests/firmware_host/test_firmware.cpp -o /tmp/upch-as7341-firmware-test
/tmp/upch-as7341-firmware-test
ARDUINO_DIRECTORIES_USER="$PWD/.arduino" arduino-cli compile --fqbn arduino:avr:mega --warnings all firmware/mega_as7341_multichannel
```

Las versiones de bibliotecas están en README.md. En este Mac se usó el `arduino-cli` incluido en Arduino IDE, en `/Applications/Arduino IDE.app/Contents/Resources/app/lib/backend/resources/arduino-cli`.

## Estado de validación física

El usuario confirmó comunicación con el Mega, recepción multicanal, patrón azul, GUI y Nokia con la configuración anterior. El nuevo control PWM de la versión 2.3.0 está verificado por pruebas y compilación, pero falta cargarlo y comprobar físicamente D11 a 0 %, 25 %, 50 % y 100 %. El modo IO Rodeo reproduce el contenido multicanal disponible; no inventa batería, TSL a 180° ni Relative Units.

La corrección de fondo, las curvas y las estadísticas nuevas están verificadas con datos simulados y evidencia bibliográfica, no con estándares reales del montaje. Falta comprobar matriz del blanco, estabilidad, repetibilidad y controles independientes; no se informa LOD/LOQ, eficiencia cuántica ni incertidumbre certificada.

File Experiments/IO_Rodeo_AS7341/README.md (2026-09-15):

# Demostración del IO Rodeo

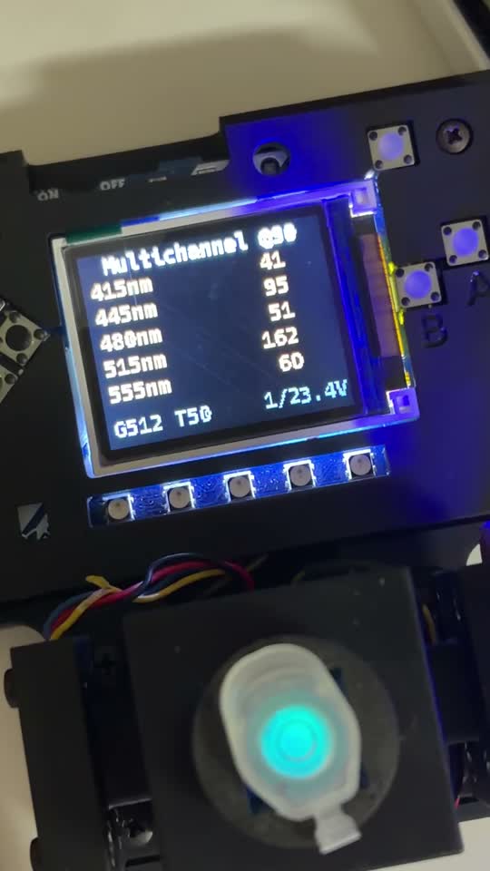
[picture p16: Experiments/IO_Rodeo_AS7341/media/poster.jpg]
IO Rodeo en funcionamiento


[Abrir el video MP4](media/demostracion_funcionamiento.mp4)

## Qué muestra

El video registra el equipo IO Rodeo encendido, la pantalla multicanal y el montaje óptico conectado. La pantalla presenta las bandas del AS7341 en páginas, mientras el conjunto mantiene el formato físico del fluorímetro.

## Firmware relacionado

Consulta [`../../Firmware/IO_Rodeo_PyBadge/v3.0_as7341/`](../../Firmware/IO_Rodeo_PyBadge/v3.0_as7341/) para el snapshot que añade `Multichannel 90` y el AS7341 a 90 grados.

## Comprobaciones de uso

1. Apaga el equipo antes de cambiar sensores o conexiones.
2. Confirma AS7341 en el canal 3 y TSL2591 en el canal 0 del PCA9546A.
3. Carga el snapshot completo en `CIRCUITPY`.
4. Inicia `Multichannel 90` y revisa ambas páginas.
5. Si aparece `OVFL`, reduce ganancia, tiempo de integración o intensidad óptica.

El video confirma operación visible del montaje. No demuestra calibración absoluta del AS7341 ni exactitud del cociente ratiométrico.

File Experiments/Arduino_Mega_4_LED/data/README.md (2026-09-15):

# Datos registrados

`records/` contiene CSV generados por la grabación de telemetría. `sessions/` conserva autoguardados de experimentos y, cuando existe, telemetría progresiva.

Antes de analizar estos archivos:

1. Comprueba que la sesión tenga identificador de muestra y configuración.
2. Separa lecturas sucesivas de réplicas experimentales completas.
3. Verifica ganancia, integración, PWM y canales.
4. Identifica blancos y exposiciones A/B cuando se use un cociente.
5. No interpoles lecturas `OVFL` ni extrapoles una curva de calibración.

Algunas sesiones son registros parciales de desarrollo. La presencia de un archivo no implica que el ensayo haya terminado o que cumpla un protocolo validado.

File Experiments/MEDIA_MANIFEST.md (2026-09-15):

# Manifiesto de medios originales

Los originales permanecen fuera del repositorio. Se registran sus hashes para comprobar que los clips proceden de los archivos correctos.

| Archivo original | Duración | Resolución y tasa | SHA-256 | Uso |
| --- | ---: | --- | --- | --- |
| `IMG_7660.MOV` | 7.518 s | 3840 x 2160, 60 fps | `97373979a640ff70cb354c0268efe7090922c1629f4382dc448e66fb32d91656` | Demostración corta del IO Rodeo |
| `IMG_7704.MOV` | 201.165 s | 3840 x 2160, 59.94 fps | `6ea71553eface19bb1c0285349036ac75526879f4405b5b395dfdda7497e571c` | Demostración del Mega y cuatro LED |

## Conversión

Los derivados se codificaron como H.264 con audio AAC, 30 fps y reproducción progresiva para facilitar su uso en GitHub. Los clips del Mega son 1920 x 1080. El video vertical del IO Rodeo es 1080 x 1920. Se retiraron los metadatos de ubicación de los derivados.

## Cortes de `IMG_7704.MOV`

| Clip | Intervalo del original |
| --- | --- |
| `01_led_azul.mp4` | 00:00.000 a 00:39.000 |
| `02_led_ambar.mp4` | 00:39.000 a 01:43.000 |
| `03_led_3.mp4` | 01:43.000 a 02:47.000 |
| `04_led_4.mp4` | 02:47.000 a 03:21.165 |

Los límites incluyen la sustitución física de cada placa LED para no perder la continuidad de la demostración.

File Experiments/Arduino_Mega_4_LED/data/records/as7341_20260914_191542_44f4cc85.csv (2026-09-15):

received_at | sequence | millis | gain | integration_time | pwm_percent | pwm_raw | page | 415 | 445 | 480 | 515 | 555 | 590 | 630 | 680 | nir | clear
2026-09-15T00:15:42.915046+00:00 | 741 | 535980 | 16x | 300ms | 15 | 38 | 0 | 399 | 185 | 2085 | 21882 | 6461 | 993 | 650 | 557 | 691 | 22030
2026-09-15T00:15:43.635001+00:00 | 742 | 536702 | 16x | 300ms | 15 | 38 | 0 | 399 | 185 | 2085 | 21882 | 6461 | 993 | 650 | 557 | 691 | 22030
2026-09-15T00:15:44.363257+00:00 | 743 | 537427 | 16x | 300ms | 15 | 38 | 0 | 399 | 185 | 2085 | 21883 | 6461 | 993 | 650 | 557 | 691 | 22031
2026-09-15T00:15:45.082473+00:00 | 744 | 538152 | 16x | 300ms | 15 | 38 | 1 | 399 | 185 | 2085 | 21882 | 6461 | 993 | 650 | 557 | 691 | 22030
2026-09-15T00:15:45.802971+00:00 | 745 | 538875 | 16x | 300ms | 15 | 38 | 1 | 399 | 185 | 2085 | 21881 | 6460 | 993 | 650 | 557 | 691 | 22030
2026-09-15T00:15:46.523459+00:00 | 746 | 539596 | 16x | 300ms | 15 | 38 | 1 | 399 | 185 | 2085 | 21880 | 6459 | 993 | 650 | 557 | 691 | 22025
2026-09-15T00:15:47.251730+00:00 | 747 | 540319 | 16x | 300ms | 15 | 38 | 1 | 399 | 185 | 2085 | 21878 | 6459 | 993 | 650 | 557 | 691 | 22026
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

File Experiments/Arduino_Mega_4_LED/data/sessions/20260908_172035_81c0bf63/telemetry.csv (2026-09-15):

received_at | sequence | millis | gain | integration_time | page | 415 | 445 | 480 | 515 | 555 | 590 | 630 | 680 | nir | clear
2026-09-08T22:26:50.319878+00:00 | 1 | 355 | 128x | 100ms | 0 | 6 | 14 | 18 | 24 | 6 | 14 | 18 | 24 | 23 | 117
2026-09-08T22:26:50.669815+00:00 | 2 | 709 | 128x | 100ms | 0 | 6 | 14 | 18 | 24 | 6 | 14 | 18 | 24 | 23 | 117
2026-09-08T22:26:51.045951+00:00 | 3 | 1063 | 128x | 100ms | 0 | 6 | 14 | 18 | 24 | 6 | 14 | 18 | 24 | 23 | 117
2026-09-08T22:26:51.396293+00:00 | 4 | 1419 | 128x | 100ms | 0 | 6 | 14 | 18 | 24 | 6 | 14 | 18 | 24 | 23 | 117
2026-09-08T22:26:51.745920+00:00 | 5 | 1773 | 128x | 100ms | 0 | 6 | 14 | 18 | 24 | 6 | 14 | 18 | 24 | 23 | 116
2026-09-08T22:26:52.094827+00:00 | 6 | 2127 | 128x | 100ms | 0 | 6 | 14 | 18 | 24 | 6 | 14 | 18 | 24 | 23 | 117
2026-09-08T22:26:52.445872+00:00 | 7 | 2482 | 128x | 100ms | 0 | 6 | 14 | 18 | 24 | 6 | 14 | 18 | 24 | 22 | 116
2026-09-08T22:26:52.820282+00:00 | 8 | 2836 | 128x | 100ms | 0 | 6 | 14 | 18 | 24 | 6 | 14 | 18 | 24 | 22 | 115
2026-09-08T22:26:53.171103+00:00 | 9 | 3190 | 128x | 100ms | 1 | 6 | 14 | 18 | 24 | 6 | 14 | 18 | 24 | 22 | 115
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

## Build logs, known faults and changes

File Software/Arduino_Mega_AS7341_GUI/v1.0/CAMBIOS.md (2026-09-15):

# Registro de cambios

## 2026-09-14 - Escala Y automática opcional

- Se añadió el botón Auto junto al límite Y. Está desactivado al abrir la GUI; se conserva el máximo fijo inicial de 2000 cuentas.
- Auto ajusta el máximo a F1-F8 con un margen del 10 % y redondeo hacia arriba. Excluye NIR, Clear y lecturas OVFL; el límite no supera 65535 cuentas.
- El estado activo se distingue por texto y color. Al desactivarlo, el último máximo queda disponible para ajuste manual. Pausar la gráfica también congela su escala automática.
- Se evita interpolar entradas y salidas de saturación para no generar valores visuales falsos. La animación entre lecturas válidas conserva su comportamiento.
- No se cambiaron ganancia, integración, PWM, datos raw, grabación ni firmware. No hace falta volver a cargar el Mega.

## 2026-09-12 - Experimentos, resultados y calidad

- Se ampliaron Experimentos y calibración con ID de muestra, exposición, capturas de blanco y señal, intensidad corregida y blancos A/B explícitos para ambos modos de cociente.
- La curva permite intensidad raw, intensidad con blanco o cociente. Cada punto conserva concentración, unidad, método y evidencia; la compatibilidad incluye ganancia, integración, PWM, canales y protocolo/exposiciones declarados.
- Se añadió Resultados y calidad: componentes raw y restas, estadísticas de ensayos completos, advertencias, inversión de curva compatible sin extrapolación, residuos y exportación de derivados a CSV.
- Se conservan las restas negativas y se distinguen lecturas de captura de réplicas completas. No se presentan LOD/LOQ, eficiencia cuántica ni incertidumbre certificada.
- Se documentaron las fórmulas, su adaptación al AS7341 y las referencias verificadas en SCIENTIFIC_NOTES.md y en la GUI.
- El JSON versión 3 conserva blancos e intensidades derivadas; los archivos versión 2 se recuperan sin inventar una firma de calibración ausente. La carga valida datos derivados contra las lecturas originales y conserva la sesión actual si el archivo es inválido.
- No se cambiaron firmware, Nokia, adquisición en vivo, curva espectral, escala, animación, ganancia, integración ni PWM.

Validación física pendiente: blancos, estándares y réplicas con el montaje real. Las pruebas de software no validan respuesta óptica, matriz ni precisión experimental.

## 2026-09-12 - Puntuación de la interfaz

- Se sustituyeron los puntos medios decorativos por comas, dos puntos o paréntesis.
- El subtítulo describe el equipo sin barras: Caracterización óptica con Arduino Mega, AS7341 y Nokia 5110.
- Se conservaron los cocientes, unidades, rutas y toda la configuración de adquisición y gráfica.

## 2026-09-11 - PWM regulable, firmware 2.3.0

Estado de partida confirmado:

- La lectura AS7341, las ganancias, los tiempos de integración, la gráfica espectral y su escala quedan congelados sin cambios.
- La salida efectiva del firmware actual es D11 con `analogWrite(64)`, equivalente a 25 %.

Cambios realizados:

- Se añadió el comando serial `set_pwm` con rango entero 0-100 %.
- La conversión usa todo el rango de Arduino: 0 % = 0, 25 % = 64 y 100 % = 255.
- La GUI incorpora **PWM LED D11** debajo de Integración y comienza en 25 %.
- `state`, telemetría y CSV incorporan `pwm_percent` y `pwm_raw` para mantener trazabilidad experimental.
- Un cambio PWM cancela una captura experimental pendiente, igual que cambiar ganancia o integración, para no mezclar condiciones ópticas.
- Cada captura registra el PWM y las curvas exigen mantener la misma configuración. En cocientes A/B se conserva por separado el PWM usado en A y en B.
- La GUI exige que el firmware anuncie la capacidad `pwm_control`; así no presenta como compatible una versión anterior que no entienda el comando.

Pendiente:

- Cargar firmware 2.3.0 en el Mega y confirmar físicamente D11 a 0 %, 25 %, 50 % y 100 %.

## 2026-09-11 - Identidad visual del encabezado

- Se reemplazó el texto `UPCH / Spectral Lab` por el logotipo institucional proporcionado y el nombre **Spectral Lab**.
- Se aplicó una tipografía serif académica, un separador discreto y márgenes compactos.
- No se modificaron la gráfica, la adquisición, el firmware ni los controles validados.

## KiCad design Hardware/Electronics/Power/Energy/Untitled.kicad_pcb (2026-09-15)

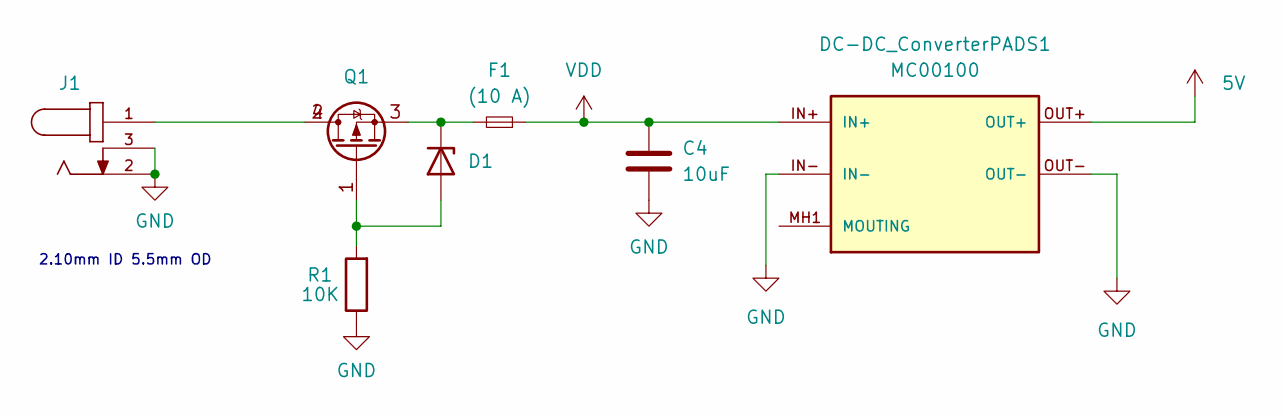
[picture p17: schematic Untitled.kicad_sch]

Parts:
C4: 10uF; C_0805_2012Metric
D1: D_Zener; MMSZ4700T1G
DC-DC_ConverterPADS1: MC00100; CONV_MC00100; PARTREV NA
F1: (10 A); 0154010.DRL; Part 0154010.DRL
J1: PJ-002A
Q1: DMP6023LE-13
R1: 10K; R_0805_2012Metric

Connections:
5V: DC-DC_ConverterPADS1.OUT+
GND: C4.2, DC-DC_ConverterPADS1.IN-, DC-DC_ConverterPADS1.OUT-, J1.2, J1.3, R1.1
unnamed: D1.2 (A), Q1.1, R1.2
unnamed: D1.1 (K), F1.2, Q1.3
unnamed: DC-DC_ConverterPADS1.MH1 (MOUTING), DC-DC_ConverterPADS1.MH2 (MOUTING)
unnamed: J1.1, Q1.2, Q1.4
VDD: C4.1, DC-DC_ConverterPADS1.IN+, F1.1

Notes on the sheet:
2.10mm ID 5.5mm OD

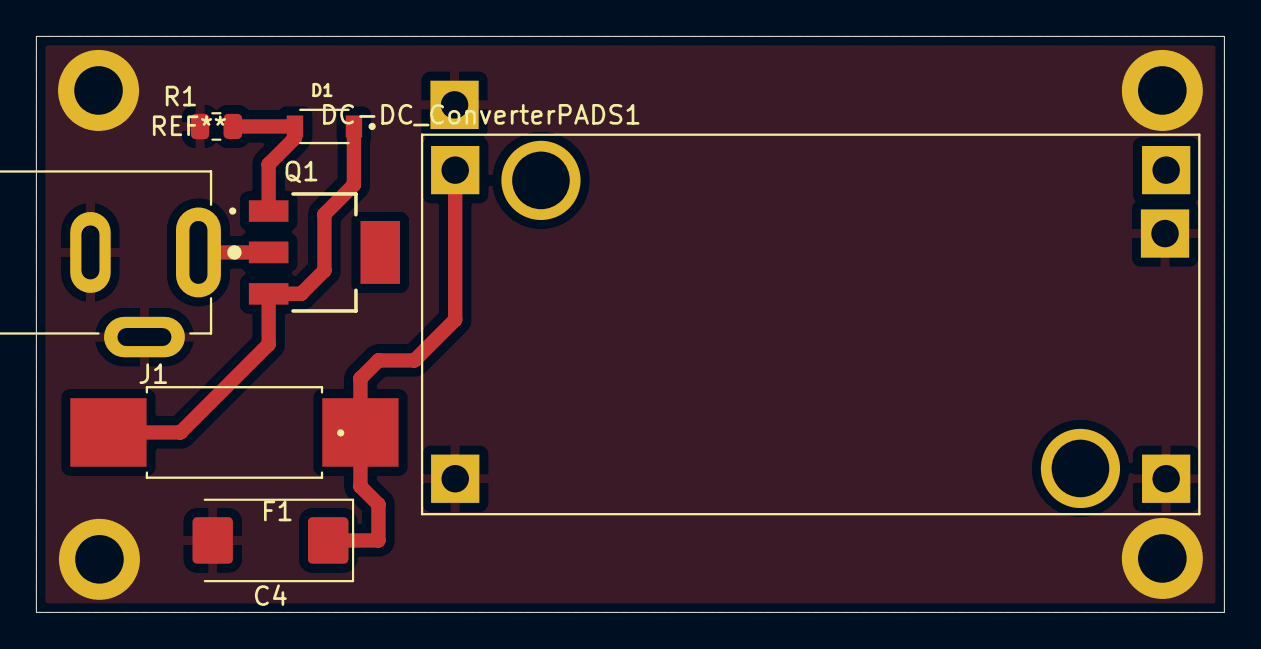
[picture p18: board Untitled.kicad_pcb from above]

Board: 2 copper layers, 66.0 x 32.0 mm, 7 parts (0 on the bottom side), 6 nets.

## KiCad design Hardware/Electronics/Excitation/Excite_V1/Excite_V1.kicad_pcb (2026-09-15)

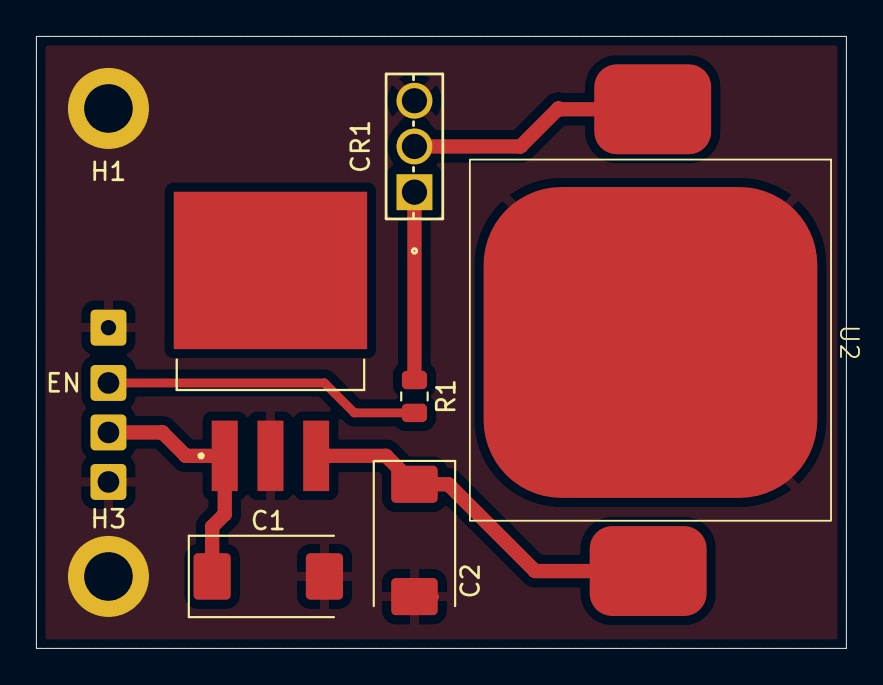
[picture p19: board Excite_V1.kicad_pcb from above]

Board: 2 copper layers, 45.0 x 34.0 mm, 9 parts (0 on the bottom side), 6 nets.

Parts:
C1, C2: 10uF; CP_EIA-7343-15_Kemet-W
CR1: BD681
EN: Enable_from_MC; SolderWire-0.25sqmm_1x01_D0.65mm_OD2mm
H1, H3: MountingHole_2.7mm_M2.5_ISO14580_Pad
R1: 10K; R_0805_2012Metric
U1: MIC29150-12WU-TR; MIC29150-12WU
U2: 10W_COB

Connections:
GND: C1.2, C2.2, CR1.3, H1.1, H3.3, U1.2 (GND), U2.3
unnamed: CR1.1, R1.2
unnamed: CR1.2, U2.1
unnamed: EN.1, R1.1
unnamed: C2.1, U1.3 (VOUT), U2.2
VDD: C1.1, U1.1 (VIN)

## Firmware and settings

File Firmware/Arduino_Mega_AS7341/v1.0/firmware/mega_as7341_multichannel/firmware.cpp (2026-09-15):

#include <Arduino.h>
#include <ArduinoJson.h>
#include <Wire.h>
#include <SPI.h>
#include <Adafruit_AS7341.h>
#include <Adafruit_GFX.h>
#include <Adafruit_PCD8544.h>
#if defined(__AVR__)
#include <avr/wdt.h>
#endif

namespace {

// Queue output without blocking reception on the Mega's small hardware UART buffer.
class SerialOutput : public Print {
 public:
  size_t write(uint8_t value) override {
    if (length_ >= sizeof(buffer_)) return 0;
    buffer_[length_++] = value;
    return 1;
  }
  size_t freeSpace() const { return sizeof(buffer_) - length_; }
  void pump() {
    size_t count = Serial.availableForWrite();
    if (count > length_) count = length_;
    if (!count) return;
    Serial.write(buffer_, count);
    length_ -= count;
    memmove(buffer_, buffer_ + count, length_);
  }
 private:
  uint8_t buffer_[1024]{};
  size_t length_{0};
};
SerialOutput tx;

constexpr uint8_t kDisplayDcPin{5};
constexpr uint8_t kDisplayCePin{4};
constexpr uint8_t kDisplayResetPin{3};
constexpr unsigned long kPageIntervalMs{3000UL};
constexpr uint16_t kOverflowCount{65535U};
constexpr uint8_t kChannelCount{10};
constexpr uint8_t kPageSize{5};
constexpr uint8_t kSerialLineCapacity{128};
constexpr uint8_t kLedPwmPin{11};
constexpr uint8_t kDefaultLedPwmPercent{25};

Adafruit_PCD8544 display{kDisplayDcPin, kDisplayCePin, kDisplayResetPin};
Adafruit_AS7341 sensor;

struct MeasurementFrame {
  uint16_t values[kChannelCount]{};
  unsigned long capturedAtMs{0};
  uint32_t sequence{0};
};

struct GainSetting {
  const char* label;
  as7341_gain_t libraryValue;
};

struct IntegrationSetting {
  const char* label;
  uint8_t atime;
  uint16_t durationMs;
};

constexpr uint16_t kSensorAstep{999};
constexpr GainSetting kGainSettings[] = {
    {"0.5x", AS7341_GAIN_0_5X}, {"1x", AS7341_GAIN_1X},
    {"2x", AS7341_GAIN_2X},     {"4x", AS7341_GAIN_4X},
    {"8x", AS7341_GAIN_8X},     {"16x", AS7341_GAIN_16X},
    {"32x", AS7341_GAIN_32X},   {"64x", AS7341_GAIN_64X},
    {"128x", AS7341_GAIN_128X}, {"256x", AS7341_GAIN_256X},
    {"512x", AS7341_GAIN_512X},
};
constexpr IntegrationSetting kIntegrationSettings[] = {
    {"50ms", 17, 50}, {"100ms", 35, 100}, {"200ms", 71, 200},
    {"300ms", 107, 300}, {"400ms", 143, 400}, {"600ms", 215, 600},
};
constexpr uint8_t kGainSettingCount = sizeof(kGainSettings) / sizeof(kGainSettings[0]);
constexpr uint8_t kIntegrationSettingCount = sizeof(kIntegrationSettings) / sizeof(kIntegrationSettings[0]);

const char* const kChannelJsonNames[kChannelCount] = {
    "415", "445", "480", "515", "555", "590", "630", "680", "nir", "clear",
};
const char* const kChannelDisplayNames[kChannelCount] = {
    "415", "445", "480", "515", "555", "590", "630", "680", "NIR", "CLR",
};

MeasurementFrame currentFrame;
uint8_t currentPage{0};
uint8_t gainIndex{8};       // 128x, como el firmware multicanal de IO Rodeo.
uint8_t integrationIndex{3}; // 300 ms, valor inicial del firmware IO Rodeo.
unsigned long lastPageChangeMs{0};
unsigned long lastMeasurementMs{0};
char serialLine[kSerialLineCapacity]{};
uint8_t serialLineLength{0};
bool discardingLine{false};
bool sensorReady{false};
bool autoPage{true};
bool channelDisplay{false};
uint8_t selectedChannel{0};
char captureId[33]{};
unsigned long captureRequestedMs{0};
uint16_t settleMs{0};
char displayLines[6][15]{};
uint8_t ledPwmPercent{kDefaultLedPwmPercent};

uint8_t pwmRawFromPercent(const uint8_t percent) {
  return static_cast<uint8_t>((static_cast<uint16_t>(percent) * 255U + 50U) / 100U);
}

void applyLedPwm() {
  analogWrite(kLedPwmPin, pwmRawFromPercent(ledPwmPercent));
}

void sendJsonString(const char* value) {
  tx.print('"');
  tx.print(value);
  tx.print('"');
}

bool applyGain(const uint8_t index) {
  return sensor.setGain(kGainSettings[index].libraryValue);
}

bool applyIntegration(const uint8_t index) {
  return sensor.setATIME(kIntegrationSettings[index].atime) &&
         sensor.setASTEP(kSensorAstep);
}

void armSensorReadWatchdog() {
#if defined(__AVR__)
  wdt_reset();
  wdt_enable(WDTO_8S);
#endif
}

void disarmSensorReadWatchdog() {
#if defined(__AVR__)
  wdt_disable();
#endif
}

// 1 = complete, 2 = failed. This intentionally mirrors Adafruit's canonical
// read-all-channels example; no channel is normalized or reconstructed here.
uint8_t readMeasurement(MeasurementFrame& frame) {
  // Adafruit 1.4.1 waits without a timeout for DATA_READY. The watchdog does
  // not alter the acquisition; it only restarts the Mega if that call hangs.
  armSensorReadWatchdog();
  const bool readSucceeded = sensor.readAllChannels();
  disarmSensorReadWatchdog();
  if (!readSucceeded || Wire.getWireTimeoutFlag()) {
    Wire.clearWireTimeoutFlag();
    return 2;
  }
  frame.values[0] = sensor.getChannel(AS7341_CHANNEL_415nm_F1);
  frame.values[1] = sensor.getChannel(AS7341_CHANNEL_445nm_F2);
  frame.values[2] = sensor.getChannel(AS7341_CHANNEL_480nm_F3);
  frame.values[3] = sensor.getChannel(AS7341_CHANNEL_515nm_F4);
  frame.values[4] = sensor.getChannel(AS7341_CHANNEL_555nm_F5);
  frame.values[5] = sensor.getChannel(AS7341_CHANNEL_590nm_F6);
  frame.values[6] = sensor.getChannel(AS7341_CHANNEL_630nm_F7);
  frame.values[7] = sensor.getChannel(AS7341_CHANNEL_680nm_F8);
  frame.values[8] = sensor.getChannel(AS7341_CHANNEL_NIR);
  frame.values[9] = sensor.getChannel(AS7341_CHANNEL_CLEAR);
  frame.capturedAtMs = millis();
  ++frame.sequence;
  return 1;
}

void renderDisplay(const MeasurementFrame& frame) {
  display.clearDisplay();
  display.setTextSize(1);
  display.setTextColor(BLACK);
  snprintf(displayLines[0], 15, "G%s T%u %u/2", kGainSettings[gainIndex].label,
           kIntegrationSettings[integrationIndex].durationMs, currentPage + 1);

  const uint8_t firstChannel = currentPage * kPageSize;
  for (uint8_t row = 0; row < kPageSize; ++row) {
    const uint8_t channelIndex = firstChannel + row;
    if (frame.values[channelIndex] >= kOverflowCount) {
      snprintf(displayLines[row + 1], 15, "%-5s %5s", kChannelDisplayNames[channelIndex], "OVFL");
    } else {
      snprintf(displayLines[row + 1], 15, "%-5s %5u", kChannelDisplayNames[channelIndex], frame.values[channelIndex]);
    }
  }
  if (channelDisplay) {
    snprintf(displayLines[0], 15, "AS7341 @90");
    snprintf(displayLines[1], 15, "CANAL %s", kChannelDisplayNames[selectedChannel]);
    if (frame.values[selectedChannel] >= kOverflowCount)
      snprintf(displayLines[2], 15, "OVFL");
    else snprintf(displayLines[2], 15, "%u", frame.values[selectedChannel]);
    snprintf(displayLines[3], 15, "cuentas ADC");
    snprintf(displayLines[4], 15, "G%s T%u", kGainSettings[gainIndex].label,
             kIntegrationSettings[integrationIndex].durationMs);
    snprintf(displayLines[5], 15, "LECTURA REAL");
  }
  display.setTextWrap(false);
  for (uint8_t row = 0; row < 6; ++row) {
    display.setCursor(0, row * 8);
    display.print(displayLines[row]);
  }
  display.display();
}

void emitState() {
  tx.print(F("{\"type\":\"state\",\"device\":\"upch-mega-as7341\",\"protocol\":2,\"firmware\":\"2.3.0\",\"sensor_ready\":"));
  tx.print(sensorReady ? F("true") : F("false"));
  tx.print(F(",\"capabilities\":[\"pwm_control\"],\"auto_page\":"));
  tx.print(autoPage ? F("true") : F("false"));
  tx.print(F(",\"gain\":"));
  sendJsonString(kGainSettings[gainIndex].label);
  tx.print(F(",\"integration_time\":"));
  sendJsonString(kIntegrationSettings[integrationIndex].label);
  tx.print(F(",\"pwm_percent\":"));
  tx.print(ledPwmPercent);
  tx.print(F(",\"pwm_raw\":"));
  tx.print(pwmRawFromPercent(ledPwmPercent));
  tx.print(F(",\"page\":"));
  tx.print(currentPage);
  tx.print(F(",\"display_mode\":"));
  sendJsonString(channelDisplay ? "channel" : "multi");
  tx.print(F(",\"display_channel\":"));
  sendJsonString(kChannelJsonNames[selectedChannel]);
  tx.print(F(",\"display_lines\":["));
  for (uint8_t row = 0; row < 6; ++row) {
    if (row) tx.print(',');
    sendJsonString(displayLines[row]);
  }
  tx.print(']');
  tx.println(F("}"));
}

void emitTelemetry(const MeasurementFrame& frame) {
  tx.print(F("{\"type\":\"telemetry\",\"sequence\":"));
  tx.print(frame.sequence);
  tx.print(F(",\"millis\":"));
  tx.print(frame.capturedAtMs);
  tx.print(F(",\"gain\":"));
  sendJsonString(kGainSettings[gainIndex].label);
  tx.print(F(",\"integration_time\":"));
  sendJsonString(kIntegrationSettings[integrationIndex].label);
  tx.print(F(",\"pwm_percent\":"));
  tx.print(ledPwmPercent);
  tx.print(F(",\"pwm_raw\":"));
  tx.print(pwmRawFromPercent(ledPwmPercent));
  tx.print(F(",\"page\":"));
  tx.print(currentPage);
  tx.print(F(",\"channels\":{"));
  for (uint8_t index = 0; index < kChannelCount; ++index) {
    sendJsonString(kChannelJsonNames[index]);
    tx.print(':');
    tx.print(frame.values[index]);
    if (index + 1 < kChannelCount) {
      tx.print(',');
    }
  }
  tx.print(F("},\"capture_id\":"));
  sendJsonString(captureId);
  tx.print(F(",\"display_mode\":"));
  sendJsonString(channelDisplay ? "channel" : "multi");
  tx.print(F(",\"display_channel\":"));
  sendJsonString(kChannelJsonNames[selectedChannel]);
  tx.print(F(",\"display_lines\":["));
  for (uint8_t row = 0; row < 6; ++row) {
    if (row) tx.print(',');
    sendJsonString(displayLines[row]);
  }
  tx.println(F("]}"));
}

void emitAck(const char* command) {
  tx.print(F("{\"type\":\"ack\",\"command\":"));
  sendJsonString(command);
  tx.println(F("}"));
}

void emitError(const char* code) {
  tx.print(F("{\"type\":\"error\",\"code\":"));
  sendJsonString(code);
  tx.println(F("}"));
}

bool commandValueMatches(const char* command, const char* value) {
  return strcmp(command, value) == 0;
}

int8_t findGainIndex(const char* command) {
  for (uint8_t index = 0; index < kGainSettingCount; ++index) {
    if (commandValueMatches(command, kGainSettings[index].label)) {
      return static_cast<int8_t>(index);
    }
  }
  return -1;
}

int8_t findIntegrationIndex(const char* command) {
  for (uint8_t index = 0; index < kIntegrationSettingCount; ++index) {
    if (commandValueMatches(command, kIntegrationSettings[index].label)) {
      return static_cast<int8_t>(index);
    }
  }
  return -1;
}

void handleCommand(const char* command) {
  // Reject trailing objects/text, even though ArduinoJson permits trailing input.
  bool quoted = false, escaped = false, finished = false;
  int depth = 0;
  for (const char* p = command; *p; ++p) {
    if (finished) {
      if (*p != ' ' && *p != '\t' && *p != '\r') { emitError("invalid_message"); return; }
    } else if (quoted) {
      if (escaped) escaped = false;
      else if (*p == '\\') escaped = true;
      else if (*p == '"') quoted = false;
    } else if (*p == '"') quoted = true;
    else if (*p == '{' || *p == '[') ++depth;
    else if (*p == '}' || *p == ']') { if (--depth == 0) finished = true; }
  }
  if (!finished || quoted) { emitError("invalid_message"); return; }
  StaticJsonDocument<384> doc;
  if (deserializeJson(doc, command) || !doc.is<JsonObject>() ||
      !doc["type"].is<const char*>() || strcmp(doc["type"], "command") != 0 ||
      !doc["command"].is<const char*>()) {
    emitError("invalid_message");
    return;
  }
  const char* name = doc["command"];
  const char* value = doc["value"] | "";
  if (strcmp(name, "get_state") == 0) {
    emitAck("get_state");
    emitState();
    return;
  }
  if (!sensorReady) { emitError("sensor_missing"); return; }
  if (strcmp(name, "begin_capture") == 0) {
    const char* token = doc["capture_id"] | "";
    if (strlen(token) != 32 || strspn(token, "0123456789abcdef") != 32 ||
        !doc["settle_ms"].is<unsigned int>() || doc["settle_ms"].as<unsigned int>() > 10000) {
      emitError("capture_invalid"); return;
    }
    strcpy(captureId, token);
    settleMs = doc["settle_ms"];
    captureRequestedMs = millis();
    emitAck("begin_capture"); return;
  }
  if (strcmp(name, "set_display_channel") == 0) {
    for (uint8_t i = 0; i < kChannelCount; ++i) {
      if (strcmp(value, kChannelJsonNames[i]) == 0) {
        selectedChannel = i; channelDisplay = true;
        emitAck(name); emitState(); return;
      }
    }
    emitError("channel_invalid"); return;
  }
  if (strcmp(name, "set_auto_page") == 0) {
    if (!doc["value"].is<bool>()) { emitError("value_invalid"); return; }
    autoPage = doc["value"];
    lastPageChangeMs = millis();
    emitState(); return;
  }
  if (strcmp(name, "next_page") == 0) {
    channelDisplay = false;
    currentPage = (currentPage + 1) % 2;
    lastPageChangeMs = millis();
    emitAck("next_page");
    emitState();
    return;
  }
  if (strcmp(name, "previous_page") == 0) {
    channelDisplay = false;
    currentPage = (currentPage + 2 - 1) % 2;
    lastPageChangeMs = millis();
    emitAck("previous_page");
    emitState();
    return;
  }
  if (strcmp(name, "set_pwm") == 0) {
    if (!doc["value"].is<unsigned int>() || doc["value"].as<unsigned int>() > 100U) {
      emitError("pwm_invalid");
      return;
    }
    captureId[0] = '\0';
    ledPwmPercent = static_cast<uint8_t>(doc["value"].as<unsigned int>());
    applyLedPwm();
    emitAck("set_pwm");
    emitState();
    return;
  }
  if (strcmp(name, "set_gain") == 0) {
    const int8_t newGainIndex = findGainIndex(value);
    if (newGainIndex < 0) {
      emitError("gain_invalid");
      return;
    }
    captureId[0] = '\0';
    if (!applyGain(newGainIndex)) {
      sensorReady = false; emitError("sensor_config_failed"); emitState(); return;
    }
    gainIndex = static_cast<uint8_t>(newGainIndex);
    emitAck("set_gain");
    emitState();
    return;
  }
  if (strcmp(name, "set_integration") == 0) {
    const int8_t newIntegrationIndex = findIntegrationIndex(value);
    if (newIntegrationIndex < 0) {
      emitError("integration_invalid");
      return;
    }
    captureId[0] = '\0';
    if (!applyIntegration(newIntegrationIndex)) {
      sensorReady = false; emitError("sensor_config_failed"); emitState(); return;
    }
    integrationIndex = static_cast<uint8_t>(newIntegrationIndex);
    emitAck("set_integration");
    emitState();
    return;
  }
  emitError("command_invalid");
}

void pollSerial() {
  tx.pump();
  while (Serial.available() > 0) {
    if (tx.freeSpace() < 600) return;
    const char received = static_cast<char>(Serial.read());
    if (discardingLine) {
      if (received == '\n') discardingLine = false;
      continue;
    }
    if (received == '\n') {
      serialLine[serialLineLength] = '\0';
      if (serialLineLength > 0) {
        handleCommand(serialLine);
      }
      serialLineLength = 0;
      continue;
    }
    if (received != '\r' && serialLineLength + 1 < kSerialLineCapacity) {
      serialLine[serialLineLength++] = received;
    } else if (serialLineLength + 1 >= kSerialLineCapacity) {
      serialLineLength = 0;
      discardingLine = true;
      emitError("line_too_long");
    }
  }
}

void showSensorError() {
  display.clearDisplay();
  display.setTextSize(1);
  display.setTextColor(BLACK);
  const char* lines[] = {"ERROR AS7341", "SIN DATOS", "REVISA I2C", "Y ALIMENTACION", "REINICIA MEGA", ""};
  display.setTextWrap(false);
  for (uint8_t row = 0; row < 6; ++row) {
    strcpy(displayLines[row], lines[row]);
    display.setCursor(0, row * 8);
    display.print(displayLines[row]);
  }
  display.display();
}

}  // namespace

void configurarPWM() {
  pinMode(kLedPwmPin, OUTPUT);
  applyLedPwm();
}

void setup() {
  Serial.begin(115200);

  // PWM inicial de 25 % en D11: equivale a analogWrite(64).
  configurarPWM();
  Wire.begin();
  Wire.setWireTimeout(25000, true);

  display.begin();
  display.setContrast(55);
  display.setRotation(2);
  display.clearDisplay();
  display.display();

  sensorReady = sensor.begin();
  if (!sensorReady) {
    showSensorError();
    emitError("sensor_missing");
    while (true) {
      pollSerial();
    }
  }

  sensorReady = applyGain(gainIndex) && applyIntegration(integrationIndex);
  if (!sensorReady) { showSensorError(); emitError("sensor_config_failed"); }
  emitState();
}

void loop() {
  pollSerial();
  if (tx.freeSpace() < 600) return;
  if (!sensorReady) return;

  const unsigned long now = millis();
  if (captureId[0] && now - captureRequestedMs < settleMs) return;
  if (autoPage && now - lastPageChangeMs >= kPageIntervalMs) {
    lastPageChangeMs = now;
    currentPage = (currentPage + 1) % 2;
  }
  // Integration already times acquisition; do not add an idle integration period.
  const uint8_t result = readMeasurement(currentFrame);
  if (result == 0) return;
  lastMeasurementMs = now;
  if (result == 2) {
    captureId[0] = '\0';
    sensorReady = false;
    showSensorError();
    emitError("sensor_read_failed");
    emitState();
    return;
  }
  renderDisplay(currentFrame);
  emitTelemetry(currentFrame);
}

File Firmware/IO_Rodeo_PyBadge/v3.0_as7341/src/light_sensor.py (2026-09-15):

import adafruit_as7341
import adafruit_tsl2591

import constants


class LightSensorAS7341:

    AS7341_MAX_COUNT = 65535
    DEFAULT_GAIN = adafruit_as7341.Gain.GAIN_128X
    DEFAULT_INTEGRATION_TIME = (107, 999)
    CHANNEL_NAMES = constants.CHANNEL_NAMES_90
    CLEAR_CHANNEL = 9

    GAIN_TO_AGAIN = {
            adafruit_as7341.Gain.GAIN_0_5X: 0.5,
            adafruit_as7341.Gain.GAIN_1X: 1.0,
            adafruit_as7341.Gain.GAIN_2X: 2.0,
            adafruit_as7341.Gain.GAIN_4X: 4.0,
            adafruit_as7341.Gain.GAIN_8X: 8.0,
            adafruit_as7341.Gain.GAIN_16X: 16.0,
            adafruit_as7341.Gain.GAIN_32X: 32.0,
            adafruit_as7341.Gain.GAIN_64X: 64.0,
            adafruit_as7341.Gain.GAIN_128X: 128.0,
            adafruit_as7341.Gain.GAIN_256X: 256.0,
            adafruit_as7341.Gain.GAIN_512X: 512.0,
            }

    def __init__(self, i2c):
        try:
            self._device = adafruit_as7341.AS7341(i2c)
        except (ValueError, OSError, RuntimeError) as error:
            raise LightSensorIOError(error)
        self.gain = self.DEFAULT_GAIN
        self.integration_time = self.DEFAULT_INTEGRATION_TIME

    @property
    def max_counts(self):
        return self.AS7341_MAX_COUNT

    @property
    def raw_values(self):
        try:
            values = list(self._device.all_channels)
            values.append(self._device.channel_nir)
            values.append(self._device.channel_clear)
        except (ValueError, OSError, RuntimeError) as error:
            raise LightSensorIOError(error)
        return tuple(values)

    @property
    def values(self):
        return self.raw_values

    @property
    def saturated_indices(self):
        return tuple(
                index
                for index, value in enumerate(self.raw_values)
                if value >= self.max_counts
                )

    @property
    def value(self):
        value = self.raw_values[self.CLEAR_CHANNEL]
        if value >= self.max_counts:
            raise LightSensorOverflow('light sensor reading > max_counts')
        return value

    @property
    def irradiance(self):
        # Señal normalizada del canal clear para conservar las pantallas de
        # latest. No representa irradiancia absoluta sin calibración óptica.
        return self.value/(self.again*self.atime)

    @property
    def gain(self):
        return self._gain

    @gain.setter
    def gain(self, value):
        self._gain = value
        self._device.gain = value

    @property
    def again(self):
        return self.GAIN_TO_AGAIN[self._gain]

    @property
    def gain_str(self):
        return constants.AS7341_GAIN_TO_STR[self.gain]

    @property
    def integration_time(self):
        return self._integration_time

    @integration_time.setter
    def integration_time(self, value):
        atime, astep = value
        self._device.atime = atime
        self._device.astep = astep
        self._integration_time = value

    @property
    def atime(self):
        atime, astep = self.integration_time
        return (atime + 1)*(astep + 1)*2.78/1000.0

    @property
    def integration_time_str(self):
        return constants.AS7341_INTEGRATION_TIME_TO_STR[
                self.integration_time
                ]


class LightSensorTSL2591:

    TSL2591_MAX_COUNT_100MS = 36863  # 0x8FFF
    TSL2591_MAX_COUNT = 65535        # 0xFFFF

    DEFAULT_GAIN = adafruit_tsl2591.GAIN_MED
    DEFAULT_INTEGRATION_TIME = adafruit_tsl2591.INTEGRATIONTIME_500MS

    GAIN_TO_AGAIN = {
            adafruit_tsl2591.GAIN_LOW: 1.0,
            adafruit_tsl2591.GAIN_MED: 24.5,
            adafruit_tsl2591.GAIN_HIGH: 400.0,
            adafruit_tsl2591.GAIN_MAX: 9200,
            }

    # (uW/cm^2) por cuenta con tiempo=1ms y ganancia=1x.
    IRRADIANCE_COEFF = (
            100.0*GAIN_TO_AGAIN[adafruit_tsl2591.GAIN_HIGH]/264.1
            )

    def __init__(self, i2c):
        try:
            self._device = adafruit_tsl2591.TSL2591(i2c)
        except (ValueError, OSError, RuntimeError) as error:
            raise LightSensorIOError(error)
        self.gain = self.DEFAULT_GAIN
        self.integration_time = self.DEFAULT_INTEGRATION_TIME
        self.channel = 0

    @property
    def max_counts(self):
        if self.integration_time == adafruit_tsl2591.INTEGRATIONTIME_100MS:
            return self.TSL2591_MAX_COUNT_100MS
        return self.TSL2591_MAX_COUNT

    @property
    def value(self):
        value = self._device.raw_luminosity[self.channel]
        if value >= self.max_counts:
            raise LightSensorOverflow('light sensor reading > max_counts')
        return value

    @property
    def values(self):
        values = self._device.raw_luminosity
        for value in values:
            if value >= self.max_counts:
                raise LightSensorOverflow('light sensor reading > max_counts')
        return values

    @property
    def lux(self):
        return self._device.lux

    @property
    def irradiance(self):
        raw_value = self._device.raw_luminosity[0]/(self.again*self.atime)
        return raw_value*self.IRRADIANCE_COEFF

    @property
    def gain(self):
        return self._gain

    @gain.setter
    def gain(self, value):
        self._gain = value
        self._device.gain = value

    @property
    def again(self):
        return self.GAIN_TO_AGAIN[self._gain]

    @property
    def gain_str(self):
        return constants.TSL2591_GAIN_TO_STR[self.gain]

    @property
    def atime(self):
        return 100.0*self._integration_time + 100.0

    @property
    def integration_time(self):
        return self._integration_time

    @integration_time.setter
    def integration_time(self, value):
        self._integration_time = value
        self._device.integration_time = value

    @property
    def integration_time_str(self):
        return constants.TSL2591_INTEGRATION_TIME_TO_STR[
                self.integration_time
                ]


class LightSensorOverflow(Exception):
    pass


class LightSensorIOError(Exception):
    pass

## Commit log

2026-09-15 Organiza avances del fluorimetro y documenta versiones
    [Detector_V1.kicad_pcb, Detector_V1.kicad_sch, Energia .step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]
2026-10-09 Inclusión de librerias DAC
2026-10-20 fix: suaviza la curva espectral web
2026-10-20 Mejorar márgenes responsivos de la GUI web
2026-10-20 Simplificar control PWM de la GUI web
